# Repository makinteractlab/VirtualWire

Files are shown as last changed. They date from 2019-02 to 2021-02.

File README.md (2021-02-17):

# VirtualWire

VirtualWire is a tool that allows users to rapidly design and modify circuits in software and have these changes instantiated in real-time as electrical connections on a physical breadboard. To achieve this, VirtualWire dynamically translates circuit design files into physical connections inside a hardware switching matrix, which handles wiring across breadboard rows and to/from an embedded Arduino. The user can interactively test, tune, and share different circuit layouts, and once satisfied, can fabricate the circuit on a permanent substrate.

Project page: [https://makinteract.kaist.ac.kr/project/virtualwire-2021](https://makinteract.kaist.ac.kr/project/virtualwire-2021)

## Reference
Woojin Lee, Ramkrishna Prasad, Seungwoo Je, Yoonji Kim, Ian Oakley, Daniel Ashbrook, and Andrea Bianchi. 2021. **VirtualWire: Supporting Rapid Prototyping with Instant Reconfigurations of Wires in Breadboarded Circuits.** In <i>Proceedings of the Fifteenth International Conference on Tangible, Embedded, and Embodied Interaction</i> (_TEI '21_). Association for Computing Machinery, New York, NY, USA, Article 4, 1–12. DOI:https://doi.org/10.1145/3430524.3440623

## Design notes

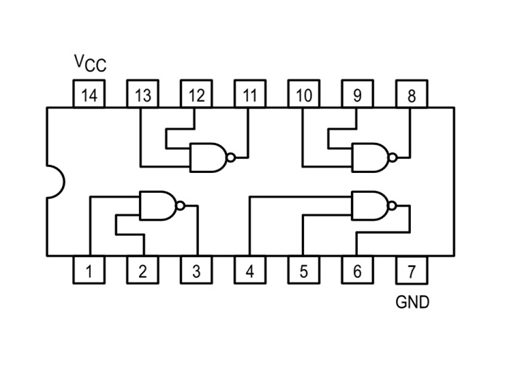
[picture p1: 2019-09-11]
Software/VirtualWire_User_App/Fritzing_Examples/ORGATE_Fritzing/74LS00-Internal-Structure.png

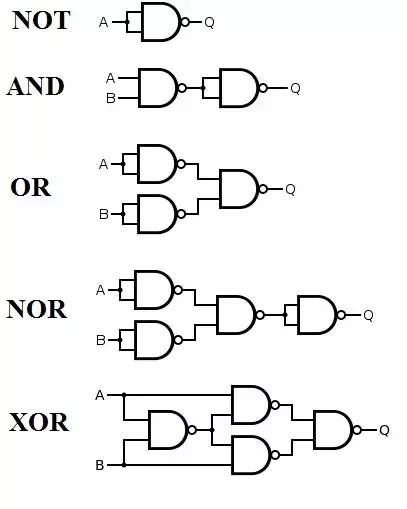
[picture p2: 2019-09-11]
Software/VirtualWire_User_App/Fritzing_Examples/ANDGATE_Fritzing/main-qimg-6664d9b8e96801605a8c257e64477ded.webp

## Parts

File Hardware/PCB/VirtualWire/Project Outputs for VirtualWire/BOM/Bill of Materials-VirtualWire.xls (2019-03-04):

Comment | Description | Designator | LibRef | Manufacturer 1 | Manufacturer Lifecycle 1 | Manufacturer Part Number 1 | Packaging | Quantity | Supplier 1 | Supplier Currency 1 | Supplier Order Qty 1 | Supplier Part Number 1 | Supplier Stock 1 | Supplier Subtotal 1 | Supplier Unit Price 1
10u | 10uF | C1 | C805_10u |  |  |  |  | 1
10u | 10uF | C2 | C805_10u |  |  |  |  | 1
330n | 330nF | C3 | C805_330n |  |  |  |  | 1
100n | 100nF | C4 | C805_100n |  |  |  |  | 1
10n | 10nF | C5 | C805_10n |  |  |  |  | 1
100n | 100nF | C6 | C805_100n |  |  |  |  | 1
100n | 100nF | C7 | C805_100n |  |  |  |  | 1
100n | 100nF | C8 | C805_100n |  |  |  |  | 1
100n | 100nF | C9 | C805_100n |  |  |  |  | 1
100n | 100nF | C10 | C805_100n |  |  |  |  | 1
100n | 100nF | C11 | C805_100n |  |  |  |  | 1
MINI_BREADBOARD | Mini Breadboard 16x2 | J1 | MINI_BREADBOARD |  |  |  |  | 1
500SSP1S1M6QEA | SWITCH SLIDE SPDT 5A 120V | J2 | SLIDE SPDT | E-Switch | Not Recommended for New Design | 500SSP1S1M6QEA | Bulk | 1 | Digi-Key | KRW | 1 | EG2478-ND | 3535 | 3190.65 | 3190.65
UNO_SHEILD |  | J3 | ARDUINO_UNO_SHIELD |  |  |  |  | 1
EPAD | Exposed PAD | J4 | EPAD |  |  |  |  | 1
PJ-002A | PJ-002 Series 2 x 6.5 mm 16 V Right Angle Through Hole Power Jack | P1 | PJ-002A | CUI | Volume Production | PJ-002A | Bulk | 1 | Digi-Key | KRW | 1 | CP-002A-ND | 163489 | 653.38 | 653.38
10k | 10k | R1 | R0805_10k |  |  |  |  | 1
10k | 10k | R2 | R0805_10k |  |  |  |  | 1
160 | 160 Ohm | R3 | R0805_160 |  |  |  |  | 1
ID | ID | R4 | R0805_10k |  |  |  |  | 1
10k | 10k | R5 | R0805_10k |  |  |  |  | 1
10k | 10k | R6 | R0805_10k |  |  |  |  | 1
160 | 160 Ohm | R7 | R0805_160 |  |  |  |  | 1
TEENSY-LC | DEV TEENSY LC 13305 | U1 | TEENSY-LC | SparkFun | Unknown | DEV-13305 |  | 1 | Digi-Key | KRW | 1 | 1568-1233-ND | 744 | 15659.25 | 15659.25
LD1085D2T33R | Fixed LDO Voltage Regulator, 6.3V to 30V, 1.3V Dropout, 3.3Vout, 3Aout, TO-263-3 | U2 | LD1085D2T33R | STMicroelectronics | Volume Production | LD1085D2T33R | Tape and Reel | 1 | Digi-Key | KRW | 1 | 497-1222-6-ND | 16248 | 1459.21 | 1459.21
L7805CDT-TR | IC REG LDO 5V 1.5A DPAK | U3 | L7805CDT-TR | STMicroelectronics | Volume Production | L7805CDT-TR | Tape and Reel | 1 | Digi-Key | USD |  | 497-7255-2-ND | 60000
WRL-13678 | WIFI ESP8266 MOD WIFI TRACE ANT | U4 | ESP8266 | SparkFun | Unknown | WRL-13678 |  | 1 | Digi-Key | KRW | 1 | 1568-1235-ND | 869 | 7568.28 | 7568.28
AD75019JPZ | SWITCH CROSSPOINT 16X16, SMD, 75019 | U5 | AD75019JPZ | Analog Devices | Volume Production | AD75019JPZ | Each | 1 | Digi-Key | KRW | 1 | AD75019JPZ-ND | 166 | 35979.25 | 35979.25
AD75019JPZ | SWITCH CROSSPOINT 16X16, SMD, 75019 | U6 | AD75019JPZ | Analog Devices | Volume Production | AD75019JPZ | Each | 1 | Digi-Key | KRW | 1 | AD75019JPZ-ND | 166 | 35979.25 | 35979.25
AD75019JPZ | SWITCH CROSSPOINT 16X16, SMD, 75019 | U7 | AD75019JPZ | Analog Devices | Volume Production | AD75019JPZ | Each | 1 | Digi-Key | KRW | 1 | AD75019JPZ-ND | 166 | 35979.25 | 35979.25

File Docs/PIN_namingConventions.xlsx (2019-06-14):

Processing/Arduino | Eagle/Firmware | Fritzing
IOREF | IOREF | ioref
RESET | RESET | RESET
A3V | A3V | 3V3
A5V | A5V | 5V
GND1 | GND1 | GND
GND2 | GND2 | GND
GND3 | GND3 | GND
VIN | VIN | VIN
A0 | A0 | A0
A1 | A1 | A1
A2 | A2 | A2
A3 | A3 | A3
A4 | A4 | A4/SDA
A5 | A5 | A5/SCL
AREF | AREF | AREF
D13 | D13 | D13/SCK
D12 | D12 | D12/MISO
D11 | D11 | D11 PWM/MOSI
D10 | D10 | D10 PWM/SS
D9 | D9 | D9 PWM
D8 | D8 | D8
D7 | D7 | D7
D6 | D6 | D6 PWM
D5 | D5 | D5 PWM
D4 | D4 | D4
D3 | D3 | D3 PWM
D2 | D2 | D2
D1 | D1 | D1/TX
D0 | D0 | D0/RX
ROW[1-16] | ROW[1-16] | pin[1-40]
DAC
ADC
PWM

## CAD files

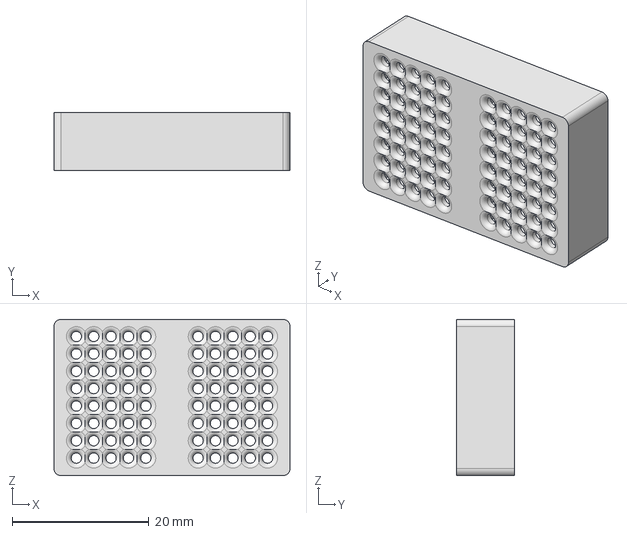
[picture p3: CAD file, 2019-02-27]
Hardware/PCB/VirtualWire/Resources/breadboard_ver3.stp
34.5 x 8.50 x 22.8 mm

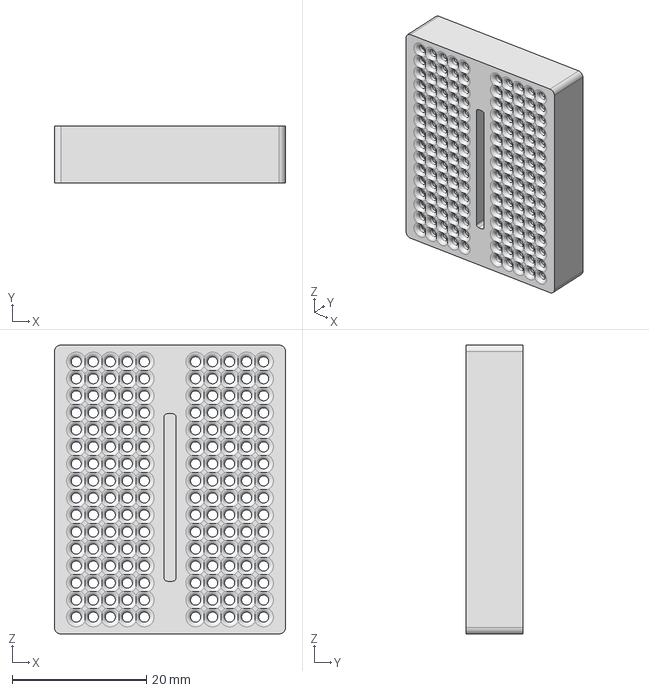
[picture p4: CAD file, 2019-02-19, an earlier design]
Hardware/PCB/VirtualWire/Resources/breadboard_ver2.stp
34.5 x 8.50 x 43.1 mm

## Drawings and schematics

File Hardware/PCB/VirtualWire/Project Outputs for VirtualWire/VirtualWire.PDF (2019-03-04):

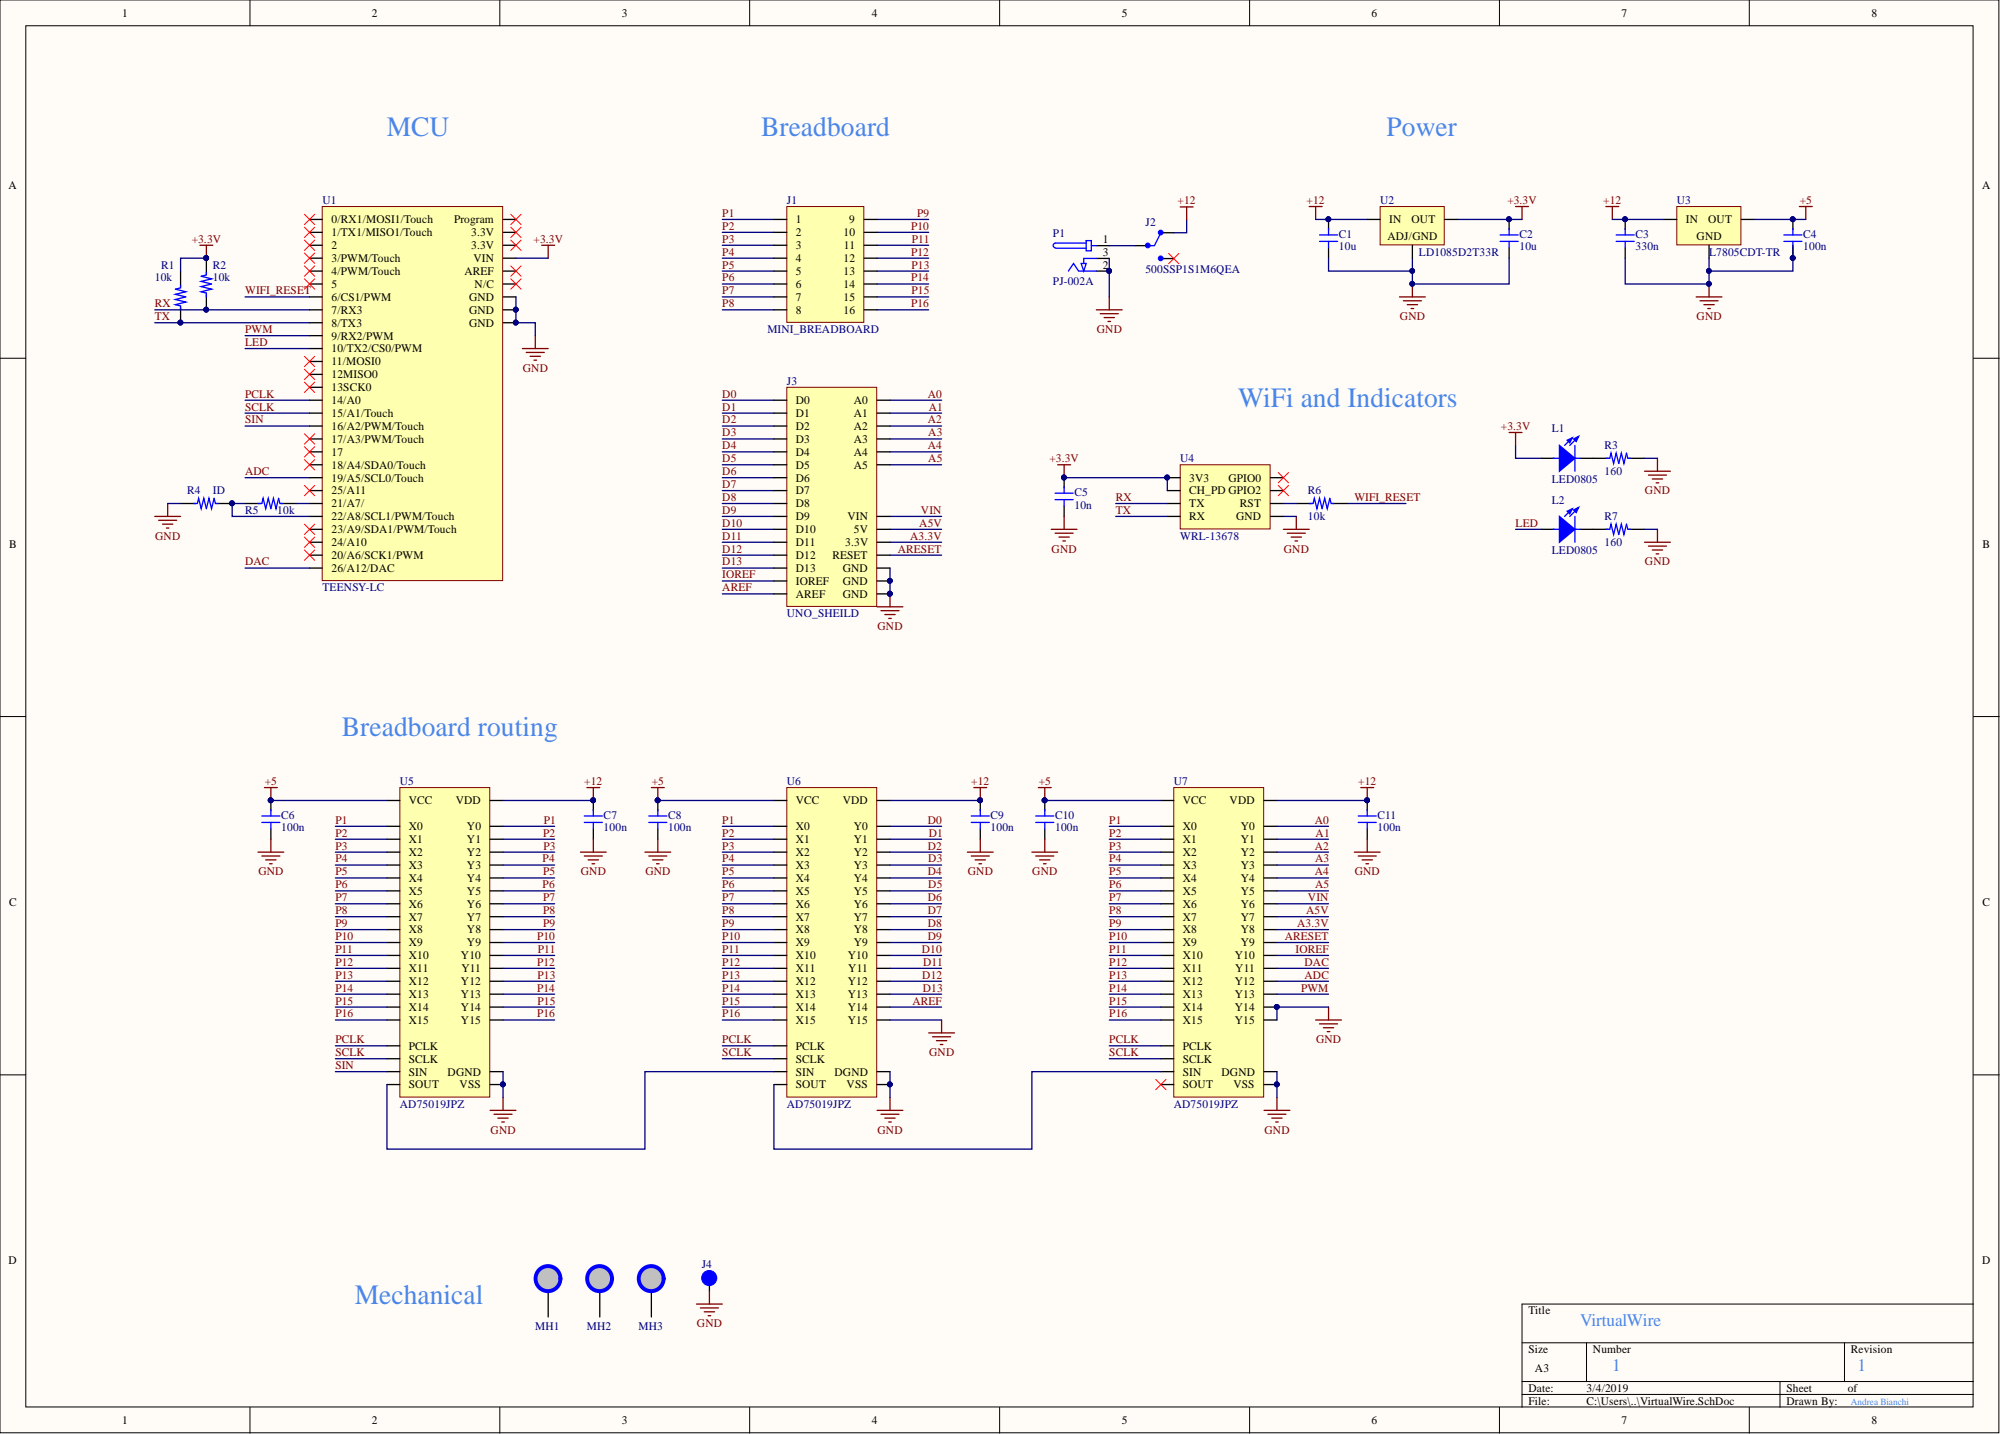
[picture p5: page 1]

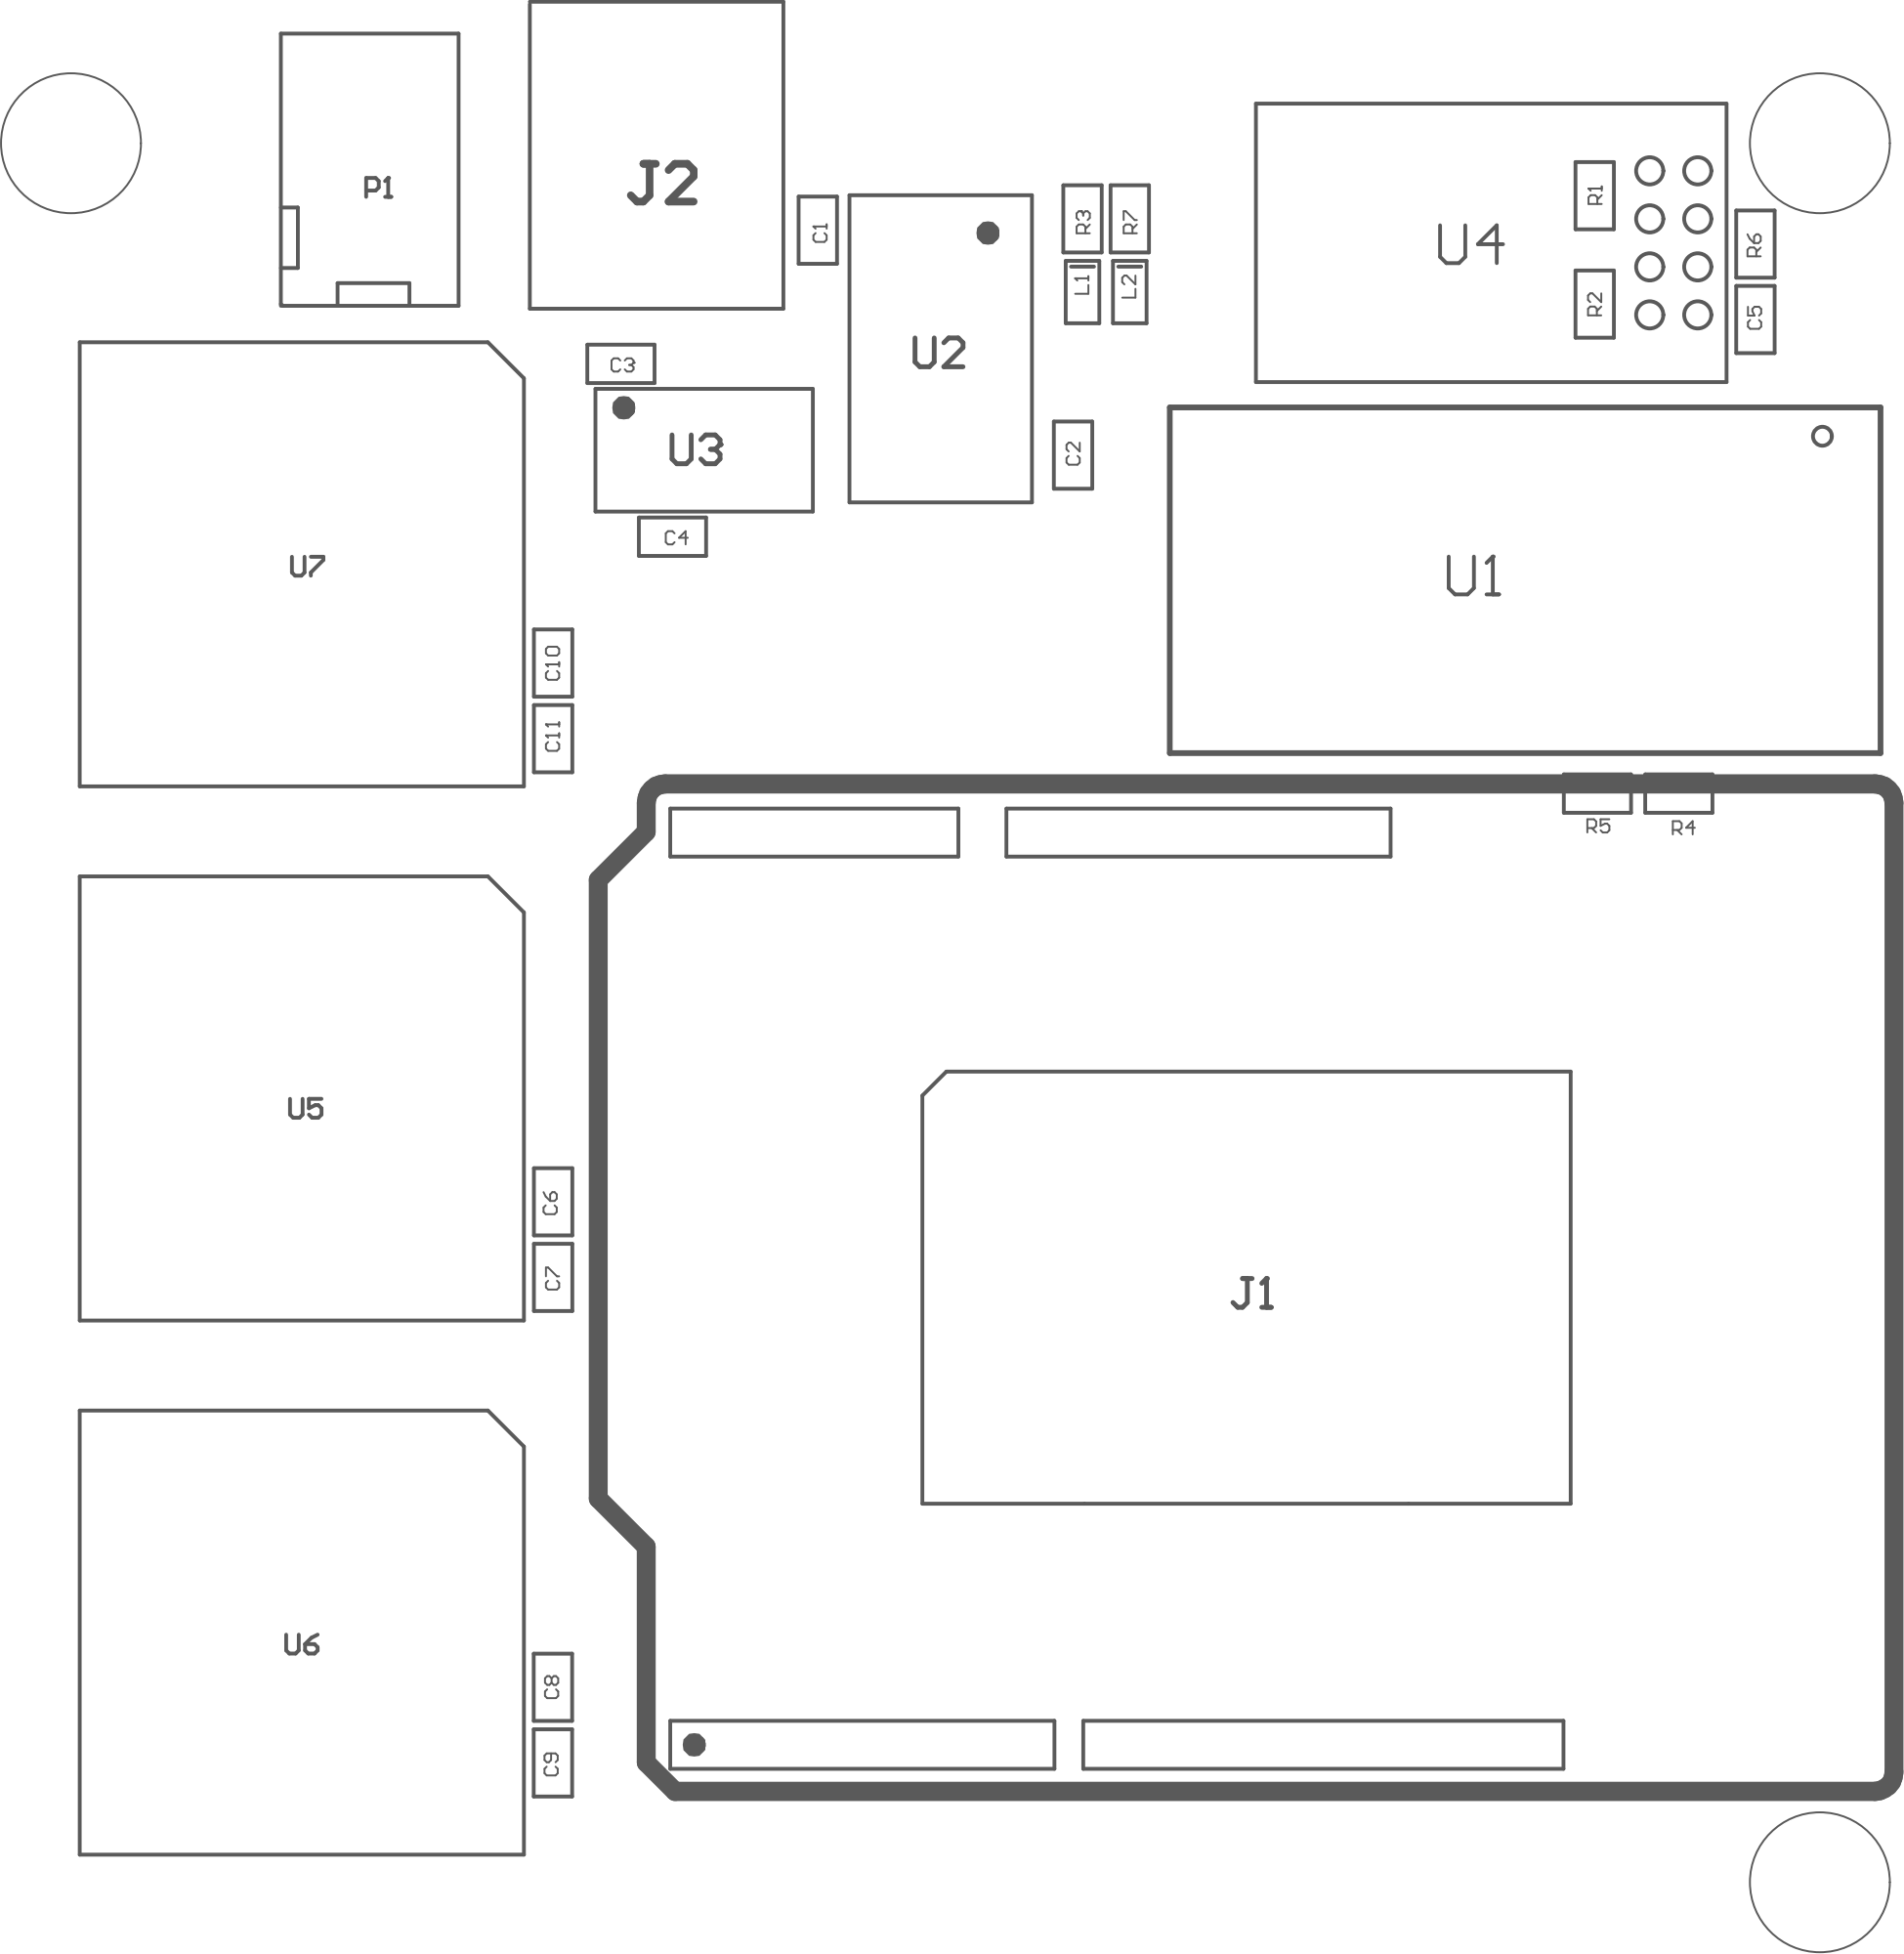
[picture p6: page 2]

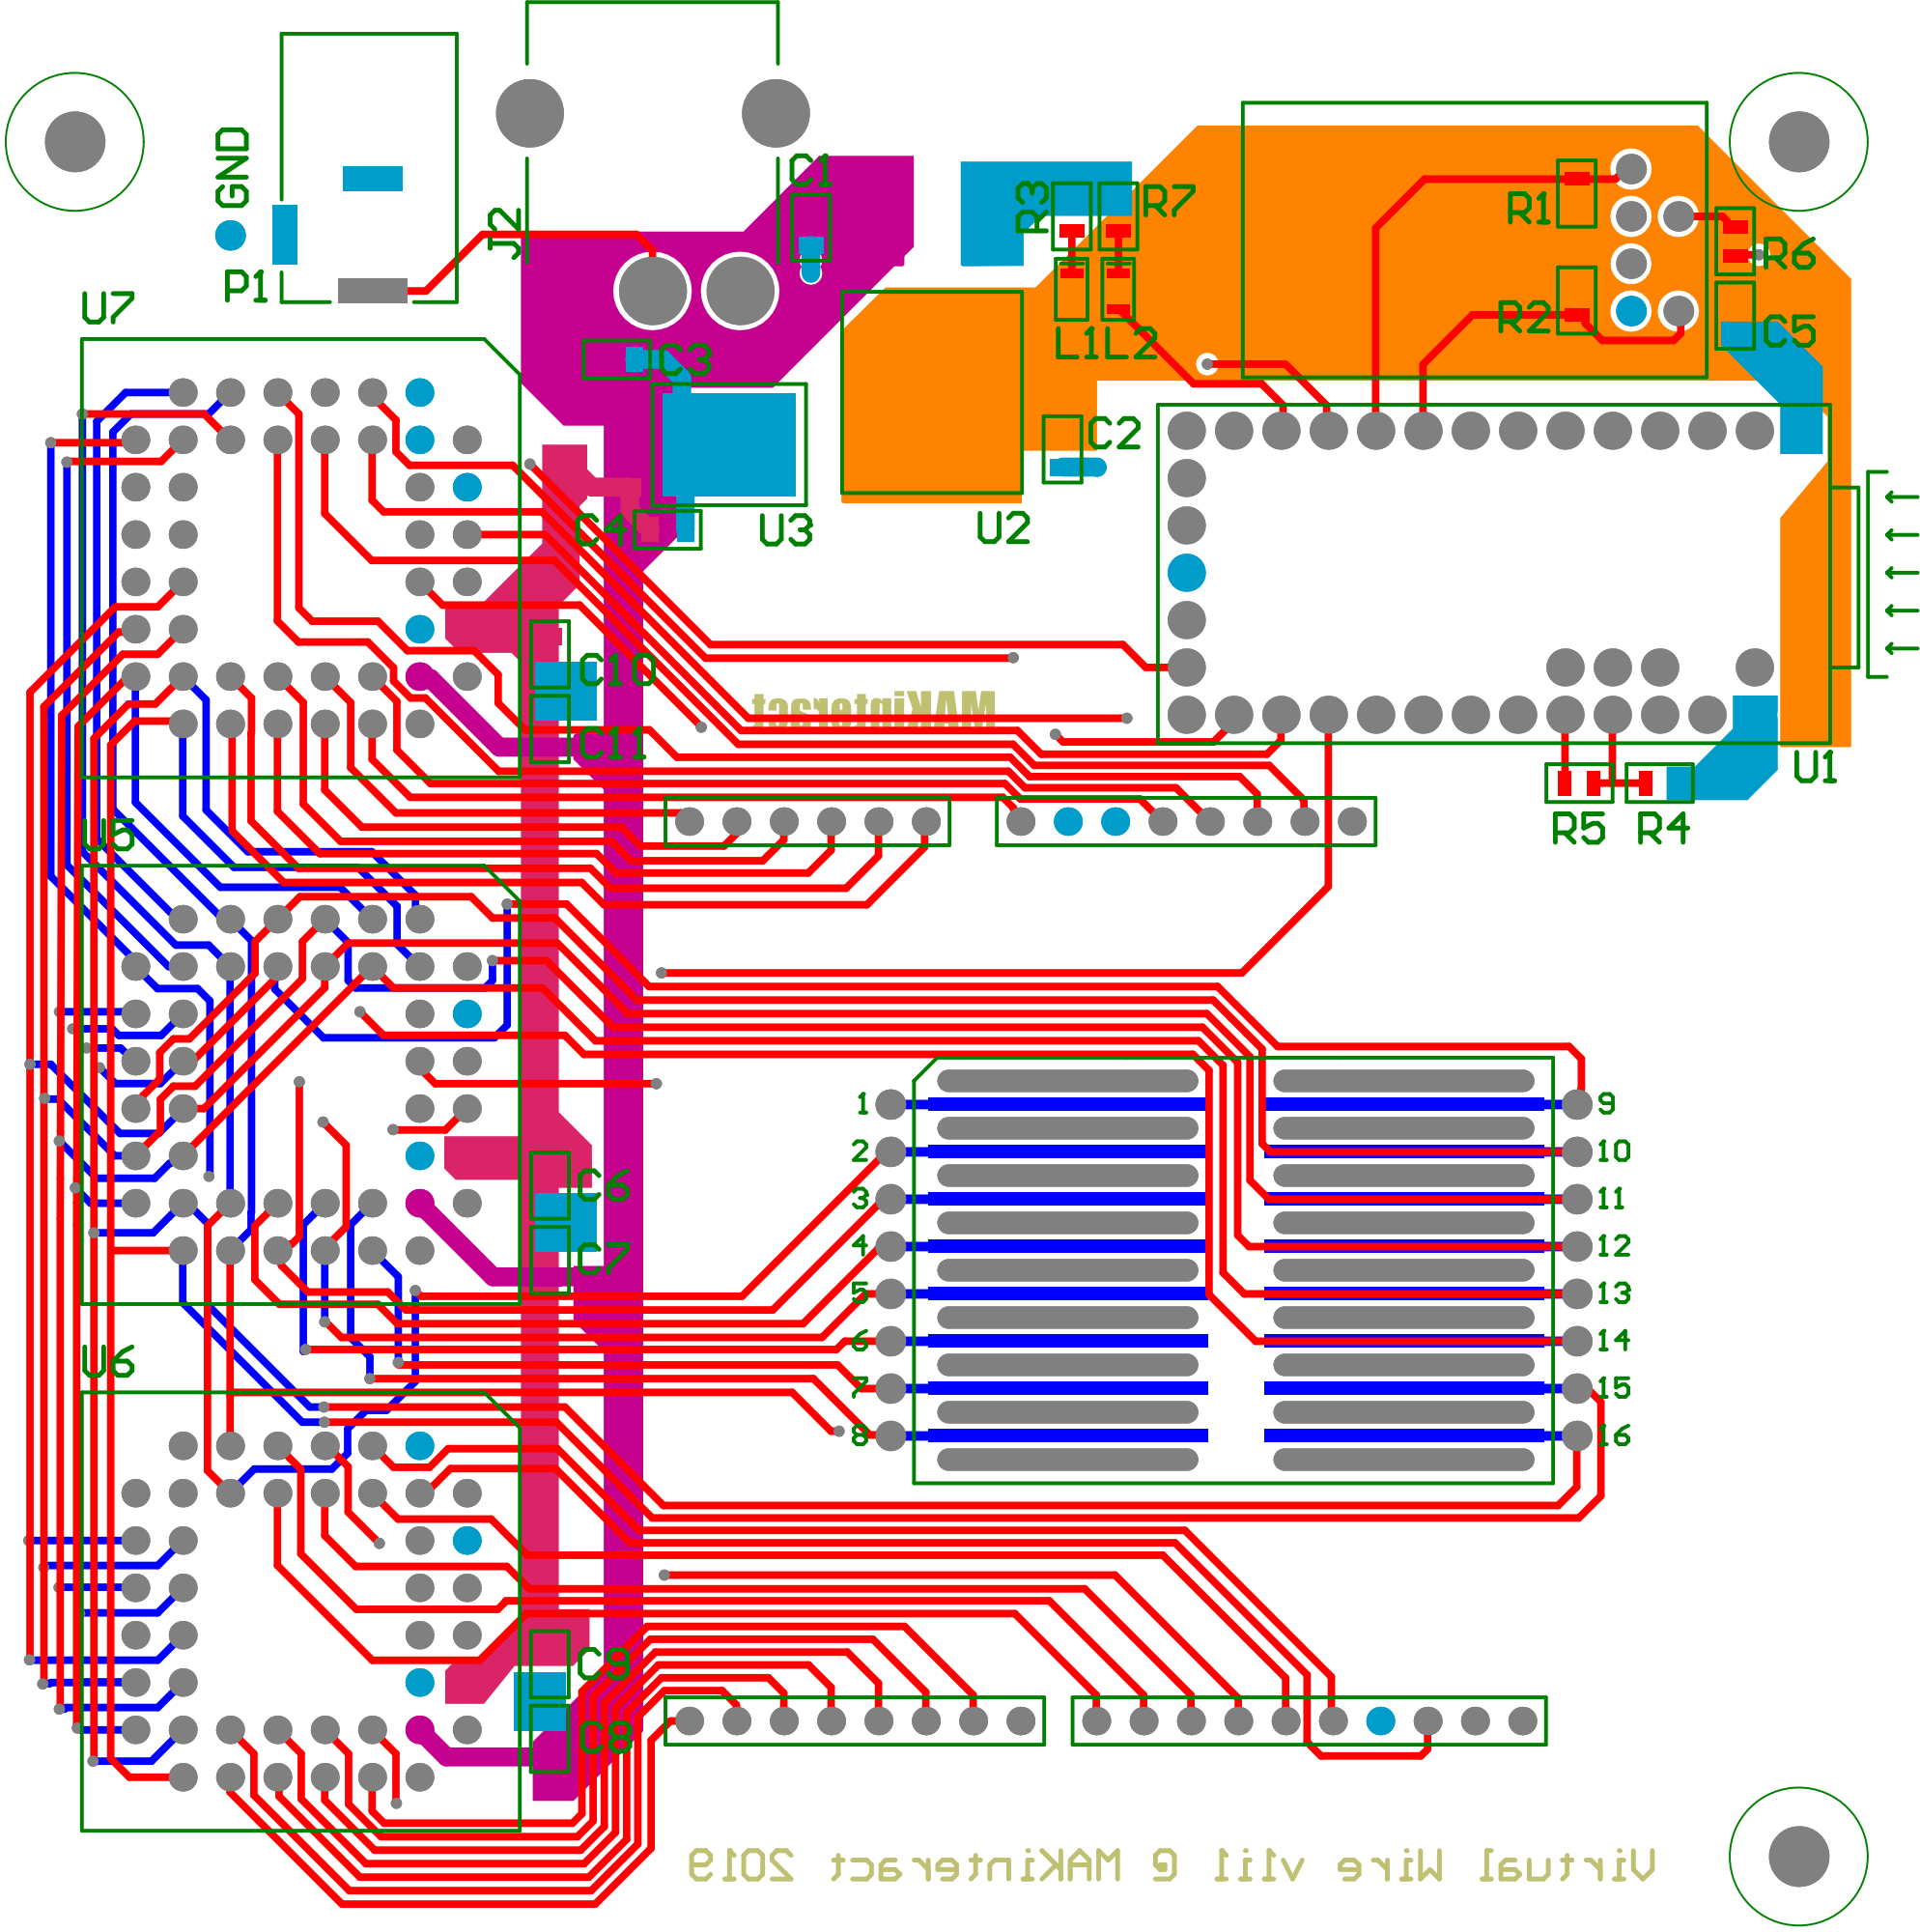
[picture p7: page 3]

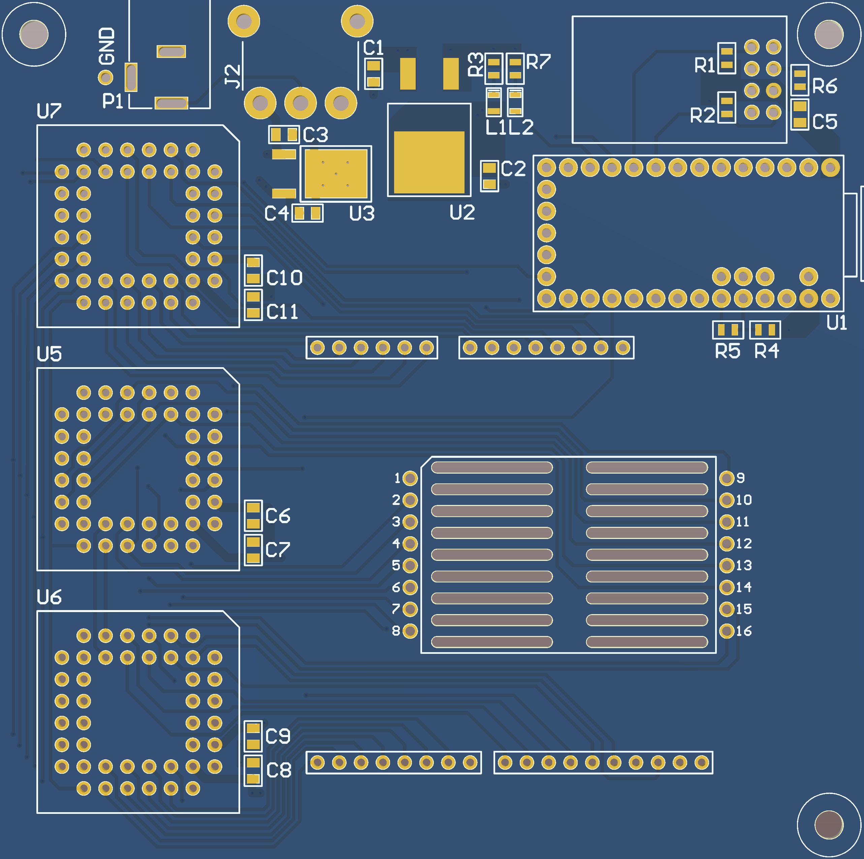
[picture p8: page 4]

Comment | Description | Designator | LibRef | Manufacturer 1 | Manufacturer Lifecycle 1 Manufacturer Part Number 1 Packaging | Quantity | Supplier 1 | Supplier Currency 1 Supplier Order Qty 1 Supplier Part Number 1 Supplier Stock 1 Supplier Subtotal 1Supplier Unit Price 1
10u | 10uF | C1 | C805_10u | | | | | 1
10u | 10uF | C2 | C805_10u | | | | | 1
330n | 330nF | C3 | C805_330n | | | | | 1
100n | 100nF | C4 | C805_100n | | | | | 1
10n | 10nF | C5 | C805_10n | | | | | 1
100n | 100nF | C6 | C805_100n | | | | | 1
100n | 100nF | C7 | C805_100n | | | | | 1
100n | 100nF | C8 | C805_100n | | | | | 1
100n | 100nF | C9 | C805_100n | | | | | 1
100n | 100nF | C10 | C805_100n | | | | | 1
100n | 100nF | C11 | C805_100n | | | | | 1
MINI_BREADBOARD | Mini Breadboard 16x2 | J1 | MINI_BREADBOARD | | | | | 1
500SSP1S1M6QEA | SWITCH SLIDE SPDT 5A 120VJ2 | | SLIDE SPDT | E-Switch | Not Recommended for New Design 500SSP1S1M6QEABulk | | | 1 | Digi-Key | KRW | 1 | EG2478-ND | 3535 | 3190.65 | 3190.65
UNO_SHEILD | | J3 | ARDUINO_UNO_SHIELD | | | | | 1
EPAD | Exposed PAD | J4 | EPAD | | | | | 1
PJ-002A | PJ-002 Series 2 x 6.5 mm 16 V Right Angle Through Hole Power Jack P1 | | PJ-002A | CUI | Volume ProductionPJ-002A | | Bulk | 1 | Digi-Key | KRW | 1 | CP-002A-ND | 163489 | 653.38 | 653.38
10k | 10k | R1 | R0805_10k | | | | | 1
10k | 10k | R2 | R0805_10k | | | | | 1
160 | 160 Ohm | R3 | R0805_160 | | | | | 1
ID | ID | R4 | R0805_10k | | | | | 1
10k | 10k | R5 | R0805_10k | | | | | 1
10k | 10k | R6 | R0805_10k | | | | | 1
160 | 160 Ohm | R7 | R0805_160 | | | | | 1
TEENSY-LC | DEV TEENSY LC 13305 | U1 | TEENSY-LC | SparkFun | Unknown | DEV-13305 | | 1 | Digi-Key | KRW | 1 | 1568-1233-ND | 744 | 15659.25 | 15659.25
LD1085D2T33R | Fixed LDO Voltage Regulator, 6.3V to 30V, 1.3V Dropout, 3.3Vout, 3Aout, TO-263-3 U2 | | LD1085D2T33R | STMicroelectronics Volume ProductionLD1085D2T33R | | | Tape and Reel | 1 | Digi-Key | KRW | 1 | 497-1222-6-ND | 16248 | 1459.21 | 1459.21
L7805CDT-TR | IC REG LDO 5V 1.5A DPAK | U3 | L7805CDT-TR | STMicroelectronics Volume ProductionL7805CDT-TR | | | Tape and Reel | 1 | Digi-Key | USD | | 497-7255-2-ND | 60000
WRL-13678 | WIFI ESP8266 MOD WIFI TRACE ANT U4 | | ESP8266 | SparkFun | Unknown | WRL-13678 | | 1 | Digi-Key | KRW | 1 | 1568-1235-ND | 869 | 7568.28 | 7568.28
AD75019JPZ | SWITCH CROSSPOINT 16X16, SMD, 75019 U5 | | AD75019JPZ | Analog Devices | Volume ProductionAD75019JPZ | | Each | 1 | Digi-Key | KRW | 1 | AD75019JPZ-ND | 166 | 35979.25 | 35979.25
AD75019JPZ | SWITCH CROSSPOINT 16X16, SMD, 75019 U6 | | AD75019JPZ | Analog Devices | Volume ProductionAD75019JPZ | | Each | 1 | Digi-Key | KRW | 1 | AD75019JPZ-ND | 166 | 35979.25 | 35979.25
AD75019JPZ | SWITCH CROSSPOINT 16X16, SMD, 75019 U7 | | AD75019JPZ | Analog Devices | Volume ProductionAD75019JPZ | | Each | 1 | Digi-Key | KRW | 1 | AD75019JPZ-ND | 166 | 35979.25 | 35979.25

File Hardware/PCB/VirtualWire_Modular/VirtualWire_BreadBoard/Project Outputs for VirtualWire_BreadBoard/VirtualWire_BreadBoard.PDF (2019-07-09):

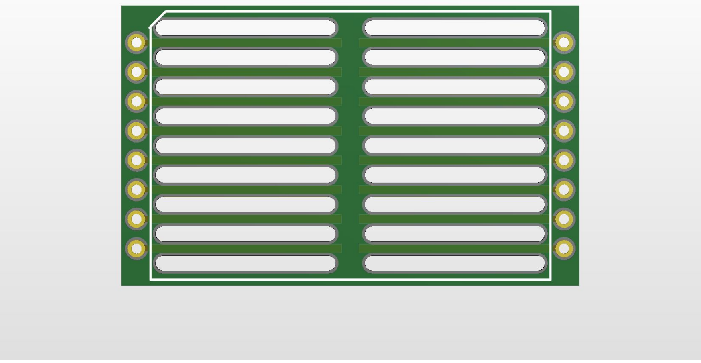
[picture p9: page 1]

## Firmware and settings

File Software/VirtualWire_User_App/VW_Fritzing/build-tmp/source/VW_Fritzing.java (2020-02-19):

import processing.core.*; 
import processing.data.*; 
import processing.event.*; 
import processing.opengl.*; 

import java.util.*; 
import java.io.*; 
import interfascia.*; 
import processing.serial.*; 

import java.util.HashMap; 
import java.util.ArrayList; 
import java.io.File; 
import java.io.BufferedReader; 
import java.io.PrintWriter; 
import java.io.InputStream; 
import java.io.OutputStream; 
import java.io.IOException; 

public class VW_Fritzing extends PApplet {





final int SERIAL_PORT_INDEX = 1;

Serial myPort;                // The serial port
String inString;              // Input string from serial port
String receivedMessage = "";  // message from hardware
String fileName;
String filePath;
String folderPath;

int serialCmdIndex = 0; 

JSONArray allCommands;

Console console;

GUIController c;
IFButton brdSignalInject_regular;
IFButton brdSignalInject_voltera;

Timer timer;
TimerTask task;

int lastChangeTime;
int thisChangeTime;
boolean firstSave = true;

public void setup(){
  
  background(200);
  
  console = new Console(0, 450, width, height-450, 9, width/50);
  
  printArray(Serial.list());
  myPort = new Serial(this, Serial.list()[SERIAL_PORT_INDEX], 115200); 
  
  c = new GUIController(this);
  
  brdSignalInject_regular = new IFButton ("brdSignalInject_regular", 30, 150, 150, 30);
  brdSignalInject_voltera = new IFButton ("brdSignalInject_voltera", 30, 190, 150, 30);
  
  brdSignalInject_regular.addActionListener(this);
  brdSignalInject_voltera.addActionListener(this);
  
  c.add(brdSignalInject_regular);
  c.add(brdSignalInject_voltera);
  
  lastChangeTime = millis();
  
  //surface.setVisible(false);
  prepareExitHandler();
  selectInput("Select a file to process:", "fileSelected");
}

public void mouseWheel(MouseEvent event) {
  int e = (int)event.getCount();
  console.scrollConsole(e);
}

public void draw(){
  
  fill(43, 48, 69);
  rect(0, 450, width, height-450);
  console.display();
  
}

public void actionPerformed (GUIEvent e){
  if(e.getSource() == brdSignalInject_regular){
    clearBrdSignals_regular();
    injectSignals_regular();
  }else if(e.getSource() == brdSignalInject_voltera){
    clearBrdSignals_voltera();
    injectSignals_voltera();
  }
}

public void fileSelected(File selection) {
  if (selection == null) {
    console.println("Window was closed or the user hit cancel.");
    return;
  }else{
    fileName = selection.getName();
    filePath = selection.getPath();
    folderPath = selection.getParent() + "\\";
    console.println("file name is: " + fileName);
    console.println("file path is: " + filePath);
    console.println("folder path is: " + folderPath);
    console.println(" ");
  }
  
  task = new FileWatcher( selection ) {
    protected void onChange( File file ) {
      
      thisChangeTime = millis();
      
      if(thisChangeTime - lastChangeTime > 5000){
        console.println("LAST CHANGE: " + lastChangeTime);
        console.println("THIS CHANGE: " + thisChangeTime);
        lastChangeTime = thisChangeTime;
        
        console.println("File "+ file.getName() +" has changed!!!");
        console.println(" ");
        
        delay(2000);
        updateConnections_FZ(filePath);
        
        delay(2000);
        updateCommands_Multi();
        
        runAllCommands();
      }
    }
  };

  timer = new Timer();
  // repeat the check every second
  timer.schedule( task, new Date(), 1000 );
}
public void injectSignals_regular(){
  ArrayList<String> allNets = pairsToNet();
  
  String[] contacts;
  String from;
  String to;
  int cnum = 1;
  
  XML brd_xml = loadXML("data/PCB/VW_PCB.brd");
  XML[] drawing = brd_xml.getChildren("drawing");
  XML[] board = drawing[0].getChildren("board");
  XML[] signals = board[0].getChildren("signals");
  
  for(int i = 0; i < allNets.size(); i++){
    contacts = split(allNets.get(i), "_");
    
    XML signal = signals[0].addChild("signal");
    signal.setString("name", "S$"+cnum);
    cnum++;
    
    String first = contacts[0];
    if(first.equals("3V3")) first = "A3V";
    if(first.equals("5V")) first = "A5V";
    
    XML contactrefFirst = signal.addChild("contactref");
    contactrefFirst.setString("element", "E$1");
    contactrefFirst.setString("pad", first);
    
    from = contacts[0];
    //if(from.equals("GND")) from = "GND1";
    if(from.equals("3V3")) from = "A3V";
    if(from.equals("5V")) from = "A5V";
      
    for(int j = 1; j < contacts.length; j++){
      
      to = contacts[j];
      //if(to.equals("GND")) to = "GND1";
      if(to.equals("3V3")) to = "A3V";
      if(to.equals("5V")) to = "A5V";
    
      XML contactrefTo = signal.addChild("contactref");
      contactrefTo.setString("element", "E$1");
      contactrefTo.setString("pad", to);
      XML wire = signal.addChild("wire");
      wire.setString("width", "0");
      wire.setString("layer", "19");
      wire.setString("extent", "1-16");
      
      wire.setString("x1", ""+getBoardCoordinate_regular(from).x);
      wire.setString("y1", ""+getBoardCoordinate_regular(from).y);
      wire.setString("x2", ""+getBoardCoordinate_regular(to).x);
      wire.setString("y2", ""+getBoardCoordinate_regular(to).y);
      
      from = to;
    }
  }
  
  saveXML(brd_xml, "data/PCB/VW_PCB.brd");
  console.println("VW_PCB.brd Signals Injected");
}

//inject via netlist made by CurrentConnections.json (VOLTERA)
public void injectSignals_voltera(){
  ArrayList<String> allNets = pairsToNet();
  
  String[] contacts;
  String from;
  String to;
  int cnum = 1;
  
  XML brd_xml = loadXML("data/PCB/VW_PCB_Voltera.brd");
  XML[] drawing = brd_xml.getChildren("drawing");
  XML[] board = drawing[0].getChildren("board");
  XML[] signals = board[0].getChildren("signals");
  
  for(int i = 0; i < allNets.size(); i++){
    contacts = split(allNets.get(i), "_");
    
    XML signal = signals[0].addChild("signal");
    signal.setString("name", "S$"+cnum);
    cnum++;
    
    String first = contacts[0];
    if(first.equals("3V3")) first = "A3V";
    if(first.equals("5V")) first = "A5V";
    
    XML contactrefFirst = signal.addChild("contactref");
    contactrefFirst.setString("element", "E$1");
    contactrefFirst.setString("pad", first);
    
    from = contacts[0];
    //if(from.equals("GND")) from = "GND1";
    if(from.equals("3V3")) from = "A3V";
    if(from.equals("5V")) from = "A5V";
    
    for(int j = 1; j < contacts.length; j++){
      
      to = contacts[j];
      //if(to.equals("GND")) to = "GND1";
      if(to.equals("3V3")) to = "A3V";
      if(to.equals("5V")) to = "A5V";
    
      XML contactrefTo = signal.addChild("contactref");
      contactrefTo.setString("element", "E$1");
      contactrefTo.setString("pad", to);
      XML wire = signal.addChild("wire");
      wire.setString("width", "0");
      wire.setString("layer", "19");
      wire.setString("extent", "1-16");
      
      wire.setString("x1", ""+getBoardCoordinate_voltera(from).x);
      wire.setString("y1", ""+getBoardCoordinate_voltera(from).y);
      wire.setString("x2", ""+getBoardCoordinate_voltera(to).x);
      wire.setString("y2", ""+getBoardCoordinate_voltera(to).y);
      
      from = to;
    }
  }
  
  saveXML(brd_xml, "data/PCB/VW_PCB_Voltera.brd");
  console.println("VW_PCB_Voltera.brd Signals Injected");
}



public void clearBrdSignals_regular(){
  XML brd_xml = loadXML("data/PCB/VW_PCB.brd");
  XML[] drawing = brd_xml.getChildren("drawing");
  XML[] board = drawing[0].getChildren("board");
  XML[] signals = board[0].getChildren("signals");
  XML[] allSignals = signals[0].getChildren("signal");
  
  for (int i = 0; i < allSignals.length; i++) {
    XML temp = signals[0].getChild("signal");
    signals[0].removeChild(temp);
  }
  
  saveXML(brd_xml, "data/PCB/VW_PCB.brd");
  console.println("VW_PCB.brd Signals Cleared");
}

public void clearBrdSignals_voltera(){
  XML brd_xml = loadXML("data/PCB/VW_PCB_Voltera.brd");
  XML[] drawing = brd_xml.getChildren("drawing");
  XML[] board = drawing[0].getChildren("board");
  XML[] signals = board[0].getChildren("signals");
  XML[] allSignals = signals[0].getChildren("signal");
  
  for (int i = 0; i < allSignals.length; i++) {
    XML temp = signals[0].getChild("signal");
    signals[0].removeChild(temp);
  }
  
  saveXML(brd_xml, "data/PCB/VW_PCB_Voltera.brd");
  console.println("VW_PCB_Voltera.brd Signals Cleared");
}

public PVector getBoardCoordinate_regular(String pad){
  float x;
  float y;
  
  switch (pad) { 
    case "SCL":
      x = 18.796f; y = 50.8f; break;
    case "SDA":
      x = 21.336f; y = 50.8f; break;
    case "AREF":
      x = 23.876f; y = 50.8f; break;
    case "GND3":
      x = 26.416f; y = 50.8f; break;
    case "D13":
      x = 28.956f; y = 50.8f; break;
    case "D12":
      x = 31.496f; y = 50.8f; break;
    case "D11":
      x = 34.036f; y = 50.8f; break;
    case "D10":
      x = 36.576f; y = 50.8f; break;
    case "D9":
      x = 39.116f; y = 50.8f; break;
    case "D8":
      x = 41.656f; y = 50.8f; break;
    case "D7":
      x = 45.72f; y = 50.8f; break;
    case "D6":
      x = 48.26f; y = 50.8f; break;
    case "D5":
      x = 50.8f; y = 50.8f; break;
    case "D4":
      x = 53.34f; y = 50.8f; break;
    case "D3":
      x = 55.88f; y = 50.8f; break;
    case "D2":
      x = 58.42f; y = 50.8f; break;
    case "D1":
      x = 60.96f; y = 50.8f; break;
    case "D0":
      x = 63.5f; y = 50.8f; break;
    case "ROW1":
      x = 17.78f; y = 35.306f; break;
    case "ROW2":
      x = 17.78f; y = 32.766f; break;
    case "ROW3":
      x = 17.78f; y = 30.226f; break;
    case "ROW4":
      x = 17.78f; y = 27.686f; break;
    case "ROW5":
      x = 17.78f; y = 25.146f; break;
    case "ROW6":
      x = 17.78f; y = 22.606f; break;
    case "ROW7":
      x = 17.78f; y = 20.066f; break;
    case "ROW8":
      x = 17.78f; y = 17.526f; break;
    case "ROW9":
      x = 54.61f; y = 35.306f; break;
    case "ROW10":
      x = 54.61f; y = 32.766f; break;
    case "ROW11":
      x = 54.61f; y = 30.226f; break;
    case "ROW12":
      x = 54.61f; y = 27.686f; break;
    case "ROW13":
      x = 54.61f; y = 25.146f; break;
    case "ROW14":
      x = 54.61f; y = 22.606f; break;
    case "ROW15":
      x = 54.61f; y = 20.066f; break;
    case "ROW16":
      x = 54.61f; y = 17.526f; break;
    case "NC":
      x = 27.94f; y = 2.54f; break;
    case "IOREF":
      x = 30.48f; y = 2.54f; break;
    case "RESET":
      x = 33.02f; y = 2.54f; break;
    case "3V3":
      x = 35.56f; y = 2.54f; break;
    case "5V":
      x = 38.1f; y = 2.54f; break;
    case "A3V":
      x = 35.56f; y = 2.54f; break;
    case "A5V":
      x = 38.1f; y = 2.54f; break;
    case "GND1":
      x = 40.64f; y = 2.54f; break;
    case "GND2":
      x = 43.18f; y = 2.54f; break;
    case "VIN":
      x = 45.72f; y = 2.54f; break;
    case "A0":
      x = 50.8f; y = 2.54f; break;
    case "A1":
      x = 53.34f; y = 2.54f; break;
    case "A2":
      x = 55.88f; y = 2.54f; break;
    case "A3":
      x = 58.42f; y = 2.54f; break;
    case "A4":
      x = 60.96f; y = 2.54f; break;
    case "A5":
      x = 63.5f; y = 2.54f; break;
    default: 
      x = 0.0f; y = 0.0f;
      break; 
  }
  
  return new PVector(x, y);
}


public PVector getBoardCoordinate_voltera(String pad){
  float x;
  float y;
  
  switch (pad) { 
    case "SCL":
      x = 18.796f; y = 45.593f; break;
    case "SDA":
      x = 21.336f; y = 45.593f; break;
    case "AREF":
      x = 23.876f; y = 45.593f; break;
    case "GND3":
      x = 26.416f; y = 45.593f; break;
    case "D13":
      x = 28.956f; y = 45.593f; break;
    case "D12":
      x = 31.496f; y = 45.593f; break;
    case "D11":
      x = 34.036f; y = 45.593f; break;
    case "D10":
      x = 36.576f; y = 45.593f; break;
    case "D9":
      x = 39.116f; y = 45.593f; break;
    case "D8":
      x = 41.656f; y = 45.593f; break;
    case "D7":
      x = 45.72f; y = 45.593f; break;
    case "D6":
      x = 48.26f; y = 45.593f; break;
    case "D5":
      x = 50.8f; y = 45.593f; break;
    case "D4":
      x = 53.34f; y = 45.593f; break;
    case "D3":
      x = 55.88f; y = 45.593f; break;
    case "D2":
      x = 58.42f; y = 45.593f; break;
    case "D1":
      x = 60.96f; y = 45.593f; break;
    case "D0":
      x = 63.5f; y = 45.593f; break;
    case "ROW1":
      x = 17.78f; y = 32.385f; break;
    case "ROW2":
      x = 17.78f; y = 29.845f; break;
    case "ROW3":
      x = 17.78f; y = 27.305f; break;
    case "ROW4":
      x = 17.78f; y = 24.765f; break;
    case "ROW5":
      x = 17.78f; y = 22.225f; break;
    case "ROW6":
      x = 17.78f; y = 19.685f; break;
    case "ROW7":
      x = 17.78f; y = 17.145f; break;
    case "ROW8":
      x = 17.78f; y = 14.605f; break;
    case "ROW9":
      x = 54.61f; y = 32.385f; break;
    case "ROW10":
      x = 54.61f; y = 29.845f; break;
    case "ROW11":
      x = 54.61f; y = 27.305f; break;
    case "ROW12":
      x = 54.61f; y = 24.765f; break;
    case "ROW13":
      x = 54.61f; y = 22.225f; break;
    case "ROW14":
      x = 54.61f; y = 19.685f; break;
    case "ROW15":
      x = 54.61f; y = 17.145f; break;
    case "ROW16":
      x = 54.61f; y = 14.605f; break;
    case "NC":
      x = 27.94f; y = 1.905f; break;
    case "IOREF":
      x = 30.48f; y = 1.905f; break;
    case "RESET":
      x = 33.02f; y = 1.905f; break;
    case "3V3":
      x = 35.56f; y = 1.905f; break;
    case "5V":
      x = 38.1f; y = 1.905f; break;
    case "A3V":
      x = 35.56f; y = 1.905f; break;
    case "A5V":
      x = 38.1f; y = 1.905f; break;
    case "GND1":
      x = 40.64f; y = 1.905f; break;
    case "GND2":
      x = 43.18f; y = 1.905f; break;
    case "VIN":
      x = 45.72f; y = 1.905f; break;
    case "A0":
      x = 50.8f; y = 1.905f; break;
    case "A1":
      x = 53.34f; y = 1.905f; break;
    case "A2":
      x = 55.88f; y = 1.905f; break;
    case "A3":
      x = 58.42f; y = 1.905f; break;
    case "A4":
      x = 60.96f; y = 1.905f; break;
    case "A5":
      x = 63.5f; y = 1.905f; break;
    default: 
      x = 0.0f; y = 0.0f;
      break; 
  }
  
  return new PVector(x, y);
}


public ArrayList<String> pairsToNet(){
  ArrayList<String> result = new ArrayList<String>();
  ArrayList<ArrayList<String>> nets = new ArrayList<ArrayList<String>>();
  ArrayList<String> pairs = new ArrayList<String>();
  
  JSONArray ccjson = loadJSONArray("data/CurrentConnections.json");
  
  for (int i = 0; i < ccjson.size(); i++) {
    
    JSONObject connection = ccjson.getJSONObject(i); 
    
    int cnum = connection.getInt("Connection Number");
    cnum++;
    String from = connection.getString("from");
    if(from.equals("A3V")) from = "3V3";
    if(from.equals("A5V")) from = "5V";
    String to = connection.getString("to");
    if(to.equals("A3V")) to = "3V3";
    if(to.equals("A5V")) to = "5V";
    
    //println(cnum + ") from: " + from + ", to: " + to);
    
    pairs.add(from + "_" + to);
  }
  
  for(int i = 0; i < pairs.size(); i++){
    String[] pair = pairs.get(i).split("_");
    String from = pair[0];
    String to = pair[1];
    boolean newNet = true;
    
    for(int j = 0; j < nets.size(); j++){
      ArrayList<String> nodes = nets.get(j);
      
      for(int k = 0; k < nodes.size(); k++){
        if(nodes.get(k).equals(from)){
          nets.get(j).add(to);
          newNet = false;
          break;
        }else if(nodes.get(k).equals(to)){
          nets.get(j).add(from);
          newNet = false;
          break;
        }
      }
      
      if(!newNet) break;
    }
    
    if(newNet){
      nets.add(new ArrayList<String>());
      nets.get(nets.size()-1).add(from);
      nets.get(nets.size()-1).add(to);
    }
  }
  
  for(int i = 0; i < nets.size(); i++){
    String str = "";
    ArrayList<String> nodes = nets.get(i);
    
    for(int j = 0; j < nodes.size(); j++){
      str = str + nodes.get(j) + "_";
    }
    
    str = str.substring(0, str.length()-1);
    
    result.add(str);
  }
  
  //for(String str: result) println(str);
  
  return result;
}
class Console{
  ArrayList<String> log;
  int xPos, yPos;
  int boxWidth, boxHeight;
  int bottomLine;
  int maxLineNum;
  int thumbThickness;
  
  Console(int xPos, int yPos, int boxWidth, int boxHeight, int maxLineNum, int thumbThickness){
    log = new ArrayList<String>();
    for(int i = 0; i < maxLineNum; i++) log.add("");
    
    this.xPos = xPos;
    this.yPos = yPos;
    this.boxWidth = boxWidth;
    this.boxHeight = boxHeight;
    this.maxLineNum = maxLineNum;
    this.thumbThickness = thumbThickness;
    
    bottomLine = log.size() - 1;
  }
  
  public int getLogSize(){ return log.size(); }
  
  public int getBottomLine(){ return bottomLine; }
  
  public void println(String line){
    if(line.length() >= 65){
      String part1 = line.substring(0, 65);
      String part2 = line.substring(65, line.length());
      log.add(part1);
      log.add(part2);
      bottomLine = log.size() - 1;
    }else{
      log.add(line);
      bottomLine = log.size() - 1;
    }
    
  }
  
  public void scrollConsole(int change){
    bottomLine = bottomLine + change;
    if(bottomLine > log.size() - 1) bottomLine = log.size() - 1;
    if(bottomLine < maxLineNum-1) bottomLine = maxLineNum-1;
  }
  
  public void display(){
    int linePos = 0;
    int lineSpacing = boxHeight/maxLineNum;
    for(int i = bottomLine - maxLineNum+1; i <= bottomLine; i++){
      fill(255);
      textSize(18);
      text(log.get(i), xPos + boxWidth/25, yPos + (linePos + 1)*lineSpacing - lineSpacing/3.5f);
      linePos++;
    }
    
    int contentHeight = log.size()*lineSpacing;
    int bottomLineHeight = (bottomLine+1)*lineSpacing;
    int thumbHeight = (int)boxHeight*boxHeight/contentHeight;
    int thumbPos = (int)bottomLineHeight*boxHeight/contentHeight;
    
    fill(200);
    //rect(xPos + 14*boxWidth/15, yPos + (int)map(thumbPos-thumbHeight, -thumbHeight/2, boxHeight-thumbHeight, 0, boxHeight-thumbHeight), boxWidth/15, thumbHeight);
    rect(xPos + boxWidth-5*thumbThickness/4, yPos + thumbPos-thumbHeight, thumbThickness, thumbHeight, thumbThickness);
  }
  
}
abstract class FileWatcher extends TimerTask {
  private long timeStamp;
  private File file;

  public FileWatcher( File file ) {
    this.file = file;
    this.timeStamp = file.lastModified();
  }

  public final  void run() {
    long timeStamp = file.lastModified();
    
    if ( this.timeStamp != timeStamp ) {
      this.timeStamp = timeStamp;
      onChange(file);
    }
  }
  
  protected abstract void onChange( File file );
}

class Wire{
  
  int id;
  String title;
  int lConn, rConn;
  int lComp, rComp;
  
  Wire(int id, String title, int lConn, int rConn, int lComp, int rComp){
    this.id = id;
    this.title = title;
    this.lConn = lConn;
    this.rConn = rConn;
    this.lComp = lComp;
    this.rComp = rComp;
  }
  
  public String getTitle(){ return title; }
  public int getLConn(){ return lConn; }
  public int getLComp(){ return lComp; }
  public int getRConn(){ return rConn; }
  public int getRComp(){ return rComp; }
  
  public String toString(){ return "id: " + id + ", title: " + title + ", lConn: " + lConn + ", rConn: " + rConn + ", lComp: " + lComp + ", rComp: " + rComp; }
}

class Map{
  int id;
  String title;
  
  Map(int id, String title){
    this.id = id;
    this.title = title;
  }
  
  public int getId(){ return id; }
  public String getTitle(){ return title; }
  
  public String toString(){ return "id: " + id + ", title: " + title; }
}

class Connection{
  
  String wireNum;
  String from, to;
  
  Connection(String wireNum, String from, String to){
    this.wireNum = wireNum;
    this.from = from;
    this.to = to;
  }
  
  public String getWireNum(){ return wireNum; }
  public String getFrom(){ return from; }
  public String getTo(){ return to; }
  
  public void changeWireNum(String wireNum){ this.wireNum = wireNum; }
  public void changeFrom(String from){ this.from = from; }
  public void changeTo(String to){ this.to = to; }
  
  public String toString(){ return wireNum + ", from: " + from + ", to: " + to; }
}

class Command{
  
  String type;
  int numberData;
  String[] data = new String[2];
  
  Command(String type, String from, String to){
    this.type = type;
    this.numberData = -1;
    this.data[0] = from;
    this.data[1] = to;
  }
  
  Command(String type, int data){
    this.type = type;
    this.numberData = data;
    this.data[0] = "";
    this.data[1] = "";
  }
  
  Command(String type){
    this.type = type;
    this.numberData = -1;
    this.data[0] = "";
    this.data[1] = "";
  }
  
  public String toString(){
    if(type.equals("reset")){ return "{\"cmd\":\"reset\"}"; }
    if(type.equals("adc")){ return "{\"cmd\":\"adc\"}" ; }
    if(type.equals("dac")){ return "{\"cmd\":\"dac\", \"data\":" + numberData + "}"; }
    if(type.equals("connect")){ return "{\"cmd\":\"connect\", \"data\": [\"" + data[0] + "\", \"" + data[1] + "\"]}"; }
    if(type.equals("disconnect")){ return "{\"cmd\":\"disconnect\", \"data\": [\"" + data[0] + "\", \"" + data[1] + "\"]}"; }
    if(type.equals("status")){ return "{\"cmd\":\"status\", \"data\": [\"" + data[0] + "\", \"" + data[1] + "\"]}"; }
    return "invalid command";
  }
}
public void serialEvent(Serial p) {
  inString = p.readStringUntil(10);
  if(inString != null){
    console.println(inString);
    serialCmdIndex++;
    
    if(serialCmdIndex < allCommands.size()){
      JSONObject command = allCommands.getJSONObject(serialCmdIndex);
      
      String runThis = command.getString("Command") + "\n";
      console.println(command.getString("Command"));
      myPort.write(runThis);
    }else{
      serialCmdIndex = 0;
      console.println("VW CONNECTIONS UPDATED!!!");
    }
  }
  
}
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
  static public void main(String[] passedArgs) {
    String[] appletArgs = new String[] { "VW_Fritzing" };
    if (passedArgs != null) {
      PApplet.main(concat(appletArgs, passedArgs));
    } else {
      PApplet.main(appletArgs);
    }
  }
}

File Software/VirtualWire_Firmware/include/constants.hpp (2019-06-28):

#ifndef __CONSTANTS__HPP__
#define __CONSTANTS__HPP__

// PINS
#define PCLK 14
#define SCLK 15
#define SIN 16
#define STATUS_LED 10
// Teensy LC
// #define DAC_PIN A12
// Teensy 3.2
#define DAC_PIN A14
#define ADC_PIN A5

// WIFI
#define BAUD_RATE 115200 
#define WIFI_RESET 6
#define IP_ADDRESS 192, 168, 0, 1
#define PORT 8080
#define BUFFER_SIZE 512

// EEPROM
#define EEPROM_SIZE 128
#define EEPROM_MEM_BASE 0
#define EEPROM_MAX_WRITE 20

// Flags
#define DEBUG 1

// Others
#define DAC_RESOLUTION 12
#define DAC_TICK_MS 1
#define DAC_MAX 4096
#define VOLT_MAX 3300
#define VOLT_MAX_HALF 1650

#define MIN_FREQ 1
#define MAX_FREQ 100

#define ADC_RESOLUTION 16
#define ADC_MAX 65536




#endif

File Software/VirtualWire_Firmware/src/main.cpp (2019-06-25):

#include <Arduino.h>
#include "constants.hpp"
#include "SwitchArray.hpp"
#include "Wifi.hpp"
#include "AppManager.hpp"



// FORWARD DECLARATIONS
void onMessageReady (const String& msg, Stream* const client);


// GLOBALS
SwitchArray switches (PCLK, SCLK, SIN);
String buffer ="";

void setup()
{
  Serial.begin(BAUD_RATE);

  // Wifi
  Wifi::getInstance().baud(BAUD_RATE).port(PORT).debug(true);
  Wifi::getInstance().registerMsgReadyCallback (&onMessageReady);
  Wifi::getInstance().init((const char*)(F("VirtualWire")), IP(IP_ADDRESS));

  // App manager
  AppManager::getInstance().init(&switches);

  // Statust OK
  AppManager::getInstance().blinkStatusLed();

  // Test Voltage example
  // AppManager::getInstance().setVoltage(1260);

  // Ready
  Serial.println("Ready");
}

void loop()
{
  // Wifi
  Wifi::getInstance().listenToRequets();  

  // Serial
  while (Serial.available())
  {
    char inChar = (char)Serial.read();
    if (inChar == '\n')
    {
      onMessageReady(buffer, &Serial);
      buffer = "";
    }
    else
    {
      buffer += inChar;
    }
  }
}


void onMessageReady (const String& msg, Stream* const client)
{
  if (!client) return;
  // Serial.println (F("Incoming message:"));
  // Serial.println (msg);
  bool ack= AppManager::getInstance().parseCommand(msg, client);
  if (!ack) buffer ="";
}

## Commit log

2019-02-19 Schematics for VirtualWire and initial PCB layout
    [VirtualWire.PcbLib, VirtualWire.PrjPcb, VirtualWire.SchDoc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]
2019-02-20 Started routing but might need to change Breadboard design
    [VirtualWire.PcbLib, VirtualWire.PrjPcb, VirtualWire.SchDoc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]
2019-02-20 New breadboard - placement redone
    [VirtualWire.PcbLib]
2019-02-27 Schematics updated to include Arduino shield
    [VirtualWire.PcbLib, VirtualWire.SchDoc, VirtualWire.SchLib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]
2019-02-27 Placement completed
    [VirtualWire.PcbDoc]
2019-02-28 First draft routing
    [VirtualWire.PcbDoc, VirtualWire.PrjPcb, VirtualWire.SchDoc]
2019-02-28 Polygon started
    [VirtualWire.PcbDoc]
2019-02-28 PCB completed
2019-02-28 Bug fixed. Need to check schematics before printing
    [VirtualWire.PcbLib, VirtualWire.SchDoc, VirtualWire.SchLib]
2019-03-04 Before changing to holed breadboard
    [VirtualWire.PcbLib, VirtualWire.SchDoc, VirtualWire.SchLib]
2019-03-04 Completed VirtualWire v1i1
    [Bill of Materials-VirtualWire.xls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]
2019-03-20 Arduino firmware started
2019-03-20 Modifications of PCB for printing
    [VirtualWire.PrjPcb]
2019-03-20 SwitchArray working
2019-03-28 WIP on new Arduino code
    Wifi server working
    WIP on Json parsing
2019-03-29 TCP communication with sockets working
2019-03-29 ADC working correctly
2019-04-11 Updated to Teensy 3.2 platform
2019-04-29 Processing server init
    [VirtualWire_tempalte.fzz]
2019-05-29 Breadboard module
    [VirtualWire_BreadBoard.GBL, VirtualWire_BreadBoard.GBO, VirtualWire_BreadBoard.GBP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]
2019-05-29 Added PDF file for docs
    [VirtualWire_BreadBoard.PcbDoc]
2019-06-14 Added tools and reference files (eagle and fritzing)
    [PIN_namingConventions.xlsx, VW_PCB_template.brd, VirtualWire_tempalte.fzz]
2019-06-24 Row Number bug fix
    Row number from [0-15] to [1-16]
    [VirtualWire_ServerPDE.pde]
2019-06-25 Reset buffer on parse fail
    [AppManager.cpp, main.cpp]
2019-07-03 Modified Eagle files
    [VW_PCB_template_Voltera.brd]
2019-07-04 New modulo breadboard with larger holes
    [VirtualWire_BreadBoard.PcbDoc, VirtualWire_BreadBoard.PcbLib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]
2019-07-09 Updated mini board for breadboard with new soldermask expansionn
    [VirtualWire_BreadBoard.PcbDoc, VirtualWire_BreadBoard.PcbLib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]
2019-08-04 Initial commit (Merged App)
    [VW.fz, VW.sch, VW_PCB.brd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]
2019-08-04 2 separate apps for fz and sch
    [555_Timer.sch, Servo_Control.sch, VW.fz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]
2019-08-04 bug fixes
    [555_Timer.sch, Servo_Control.sch, VW.fz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]
2019-08-05 eagle app visualizer polishing
    [VW_PCB.brd, VW_PCB_Voltera.brd]
2019-08-24 polishing, bug fixes, Examples added
    [555_Timer.sch, Music_Sync_Voltera.brd, Servo_Control.sch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]
2019-08-31 visualize wires in eagle app
    [VW_PCB.brd]
2020-02-19 Added Virtual Wire standalone processing app
